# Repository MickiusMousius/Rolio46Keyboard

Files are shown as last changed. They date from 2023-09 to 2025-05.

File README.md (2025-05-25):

# Introduction
The Rolio46 is now at the version 1.1 release! This repo contains all the design files so you can build your own Rolio46.

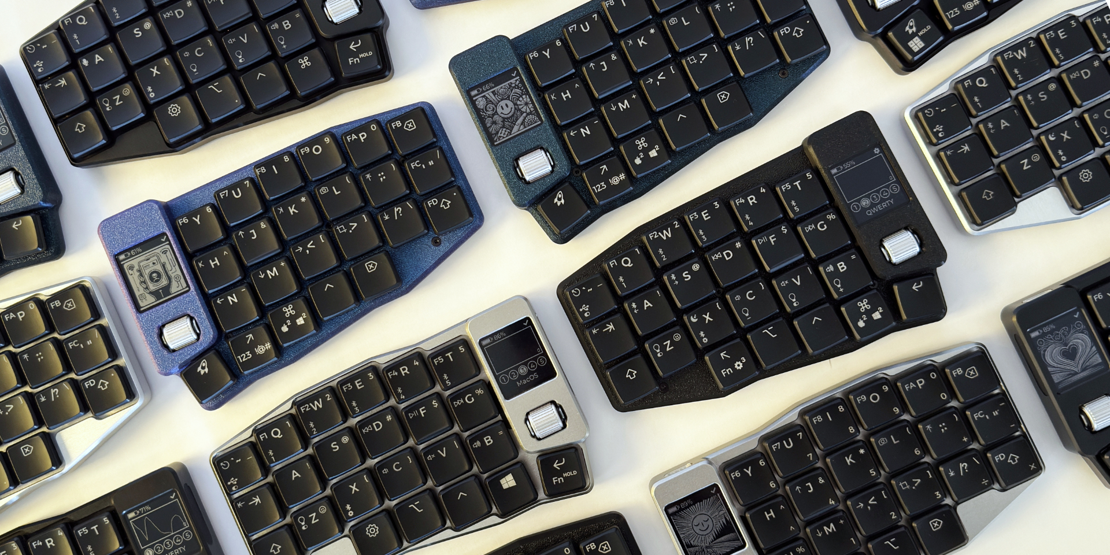
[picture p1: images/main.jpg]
Rolio46


If you'd like to build your own Rolio46 you can find resources at the following two links:
 * [RolioFirmware](https://github.com/MickiusMousius/RolioFirmware) - Firmware & user documentation for the Rolio46
 * [Keydio.io](https://keydio.io) - Online store to buy a complete kit or just some parts to build your own Rolio46

# Features
The keyboard itself:
- Fully wireless thanks to the awesome [ZMK Project](https://zmk.dev)
- Support for [ZMK Studio](https://zmk.studio/download)
- Excellent battery life, I've personally been getting 4+ weeks before it needs charging
- A low profile, compact choc spaced form factor that is similar to the Corne
- Additional "Sometimes" buttons on the bottom row just like the Sofle
- Horizontal roller encoders on both halves
- A backlight that is efficient enough to be used on battery
- A robust chassis so that it can be treated like a normal keyboard
  - An FDM version for at home low cost at home production
  - A CNC option for a slick look and very premium feel
- A travel case that can easily be made using any FDM printer

ZMK Key map & Custom key caps:
- Up to five memorized bluetooth profiles and a wired mode
- MacOS and Windows layouts as part of the key map to keep the "same" handy behaviors in both OSs
- Able to memorize a specific OS layout for each profile, when you change bluetooth profiles it'll remember whether to use a Windows or MacOS layout
- All of the symbols and special behaviors can be accessed using at most two keys.
- The key caps are fully customized and match the ZMK key map thanks to [FKCaps](https://fkcaps.com/custom/UCR89J?a=KeydioDiscount)
- The settings keys and different modes are documented in the key caps themselves (easy to learn).

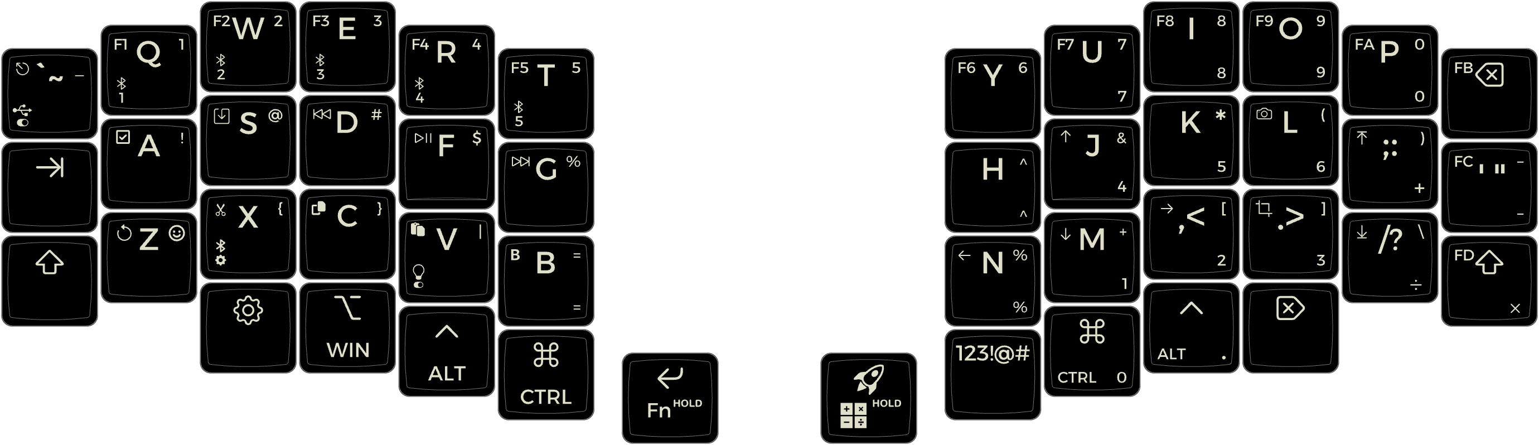
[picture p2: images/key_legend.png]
Version 1.1 Key Caps (https://fkcaps.com/custom/UCR89J?a=KeydioDiscount)
  

# Firmware

You can download the latest firmware from here: [Rolio46 Firmware](https://github.com/MickiusMousius/RolioFirmware)

When you push a change to your fork a GitHub action will create a new firmware build for you.

If you want to do basic layout customization then [ZMK Studio](https://zmk.studio/download) should be all you need.

# Build Resources
In order to build a Rolio46 you will need 5 main sub assemblies, the links below provide information about the different sub assemblies:
 * [The controller](doc/controller.md)
 * [The display](doc/display.md)
 * [The battery](doc/battery.md)
 * [The shield](pcb/README.md)
 * [The chassis](chassis/README.md)

The shield and chassis are the sub assemblies that are most unique to this project, all of the other sub assemblies are fungible.

# Other Components

<ins>Keycaps</ins>

This keyboard has been designed to use MBK caps. You should however be able to use any Choc compatible compatible caps.

You can order a set of custom key caps from a number of possible suppliers too.

I have a design at FKCaps that has the key map of this board integrated into the keys. The link for this key cap set can be found [HERE](https://fkcaps.com/custom/UCR89J?a=KeydioDiscount).

<ins>Switches</ins>

The Rolio46 is designed for use with Choc V1 switches, these can be purchased from many different vendors. My personal favorite switch is the "Choc Sunset" switch.

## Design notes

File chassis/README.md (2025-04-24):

# Introduction

This folder contains a designs and manufacturing files for the Rolio46 keyboard chassis.

The folders within here are described below.

## Electronics

This contains STEP file models with the electronics and PCB. These can be used when creating new chassis or modifying the existing models.

## CNC

This is by far the most expensive of the two options. It is also the most aesthetically pleasing, rigid and durable choice.

It does have the drawback of being the heaviest.

More information and preview images can be found in the [CNC Section](cnc/README.md).

## FDM

Contains design files for a FDM 3D printed chassis.

This is the most accessible manufacturing option and the cheapest.

The largest drawback of this manufacturing technique is that layer lines may be visible. Additionally the chassis may not be as rigid as desired depending on the filament used.

More information and example images can be found in the [FDM Section](fdm/README.md).

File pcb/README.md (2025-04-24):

# Introduction

This folder contains the KiCad 7 PCB design files for the left and right shield boards of the Rolio 46.

# Ordering The PCBs from JLCPCB

Inside the "Left" and "Right" folders there are "Gerbers" zips. These are gerber files that have been prepared for use with JLCPCB.

The following settings were used when ordering:
* Base Material:	FR-4
* Layers:	2
* Delivery Format:	Single PCB
* PCB Thickness:	1.6
* Impedance Control:	No	
* PCB Color:	Black
* Silkscreen:	White
* Via Covering:	Tented
* Surface Finish:	HASL(with lead)
* Deburring/Edge rounding:	No
* Outer Copper Weight:	1 oz
* Gold Fingers:	No
* Flying Probe Test:	Fully Test
* Castellated Holes:	No
* Remove Order Number:	No
* 4-Wire Kelvin Test:	No
* Paper between PCBs:	No
* Appearance Quality:	IPC Class 2 Standard
* Silkscreen Technology:	Ink-jet/Screen Printing Silkscreen
* Board Outline Tolerance:	±0.2mm(Regular)

Ordering is possible with other suppliers, however you should regenerate the Gerber files according to the manufacturer's requirements.

<br/>

# Required Components

All of the components in the below table are required to build the shield assembly.

| Quantity  | Description  | Ref  | Value  | Supplier  |
|:---|:---|:---|:---|:---|
| 48 | 75V 0.15A Fast Switching Diode, SOD-123 | D1-D29 | 1N4148W | [Aliexpress](https://www.aliexpress.com/item/4000685043735.html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 ) |
| 2  | Machine sockets and pins | - | - | [Typeractive](https://typeractive.xyz/products/machine-sockets-and-pins?_pos=1&_sid=3c03709e0&_ss=r) |
| 2 | Surface mount push button switch, generic, two pins | RESET1 | - | [Aliexpress](https://www.aliexpress.com/item/1005004297433455.html?spm=a2g0o.order_list.order_list_main.136.675e1802ITKJQ5 ) (I used "Option 4")  |
| 2  | Surface mount DIP Switch, Single Pole Single Throw (SPST) switch, small symbol | SW4  | - | [Aliexpress](https://www.aliexpress.com/item/4000685483225.html?spm=a2g0o.order_list.order_list_main.177.675e1802ITKJQ5) |
| 2  | EVQWGD001 Rotary encoder, dual channel, incremental quadrate outputs, with switch  | RE_1  | EVQWGD001  | [Aliexpress](https://www.aliexpress.com/item/1005004320540116.html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 ) |
| 4  | 0805 Surface mount capacitors  | C1, C2  | 100nF  | [Aliexpress](https://www.aliexpress.com/item/32888863725.html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) |
| 46  | Kailh Choc hot swap sockets PG1350 | - | -  | [Aliexpress](https://www.aliexpress.com/item/1005003908487064.html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) |

<br/>

# Optional Backlight Components

The parts in the below table are only needed for the backlight, if you do not want a backlight they can be omitted from your build to save some money.

| Quantity  | Description  | Ref  | Value  | Supplier  |
|:---|:---|:---|:---|:---|
| 2 | 30V Vds, 5.7A Id, N-Channel MOSFET, SOT-23  | Q1 | AO3400A | [Aliexpress](https://www.aliexpress.com/item/33013971929.html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)  |
| 2 | 0805 Surface mount resistor  | R1  | 470Ω  | [Aliexpress](https://www.aliexpress.com/item/1005001794062302.html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) |
| 2 | 0805 Surface mount resistor  | R2  | 10kΩ  | [Aliexpress](https://www.aliexpress.com/item/1005001794062302.html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) |
| 46 | 0805 Surface mount resistor  | R3-R25 | 680Ω  | [Aliexpress](https://www.aliexpress.com/item/1005001794062302.html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) |
| 46  | 0805 Surface mount LED  | LED1 - LED23  | - | [Aliexpress](https://www.aliexpress.com/item/1005004341345794.html?spm=a2g0o.order_list.order_list_main.25.675e1802ITKJQ5 )  |

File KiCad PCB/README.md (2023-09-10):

# Introduction

This folder contains the KiCad 7 PCB design files for the left and right halves of the Rolio Keyboard.

# Ordering

Inside the "Left" and "Right" folders there are "Gerbers" folders. These are gerber files that have been prepared for use with JLCPCB.

The two "Gerbers" folders can be zipped independently and uploaded to JLCPCB for ordering.

The following settings were used when ordering:
* Base Material:	FR-4
* Layers:	2
* Delivery Format:	Single PCB
* PCB Thickness:	1.6
* Impedance Control:	No	
* PCB Color:	Black
* Silkscreen:	White
* Via Covering:	Tented
* Surface Finish:	HASL(with lead)
* Deburring/Edge rounding:	No
* Outer Copper Weight:	1 oz
* Gold Fingers:	No
* Flying Probe Test:	Fully Test
* Castellated Holes:	No
* Remove Order Number:	No
* 4-Wire Kelvin Test:	No
* Paper between PCBs:	No
* Appearance Quality:	IPC Class 2 Standard
* Silkscreen Technology:	Ink-jet/Screen Printing Silkscreen
* Board Outline Tolerance:	±0.2mm(Regular)

Ordering is possible with other suppliers, however you should regenerate the Gerber files according to the manufacturers requirements.

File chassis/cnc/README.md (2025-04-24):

# Introduction

This section contains all of the files and information that is needed to manufacture a CNC Rolio46.1/46.2 chassis.

The STEP files are the original CAD files, these are made available so that modifications can easily be made. If the STEP files from the Electronics folder are imported too it will be possible to see the clearances for various parts.

# Example

Purple backlight LED's with dark anodized aluminium & tenting stand.

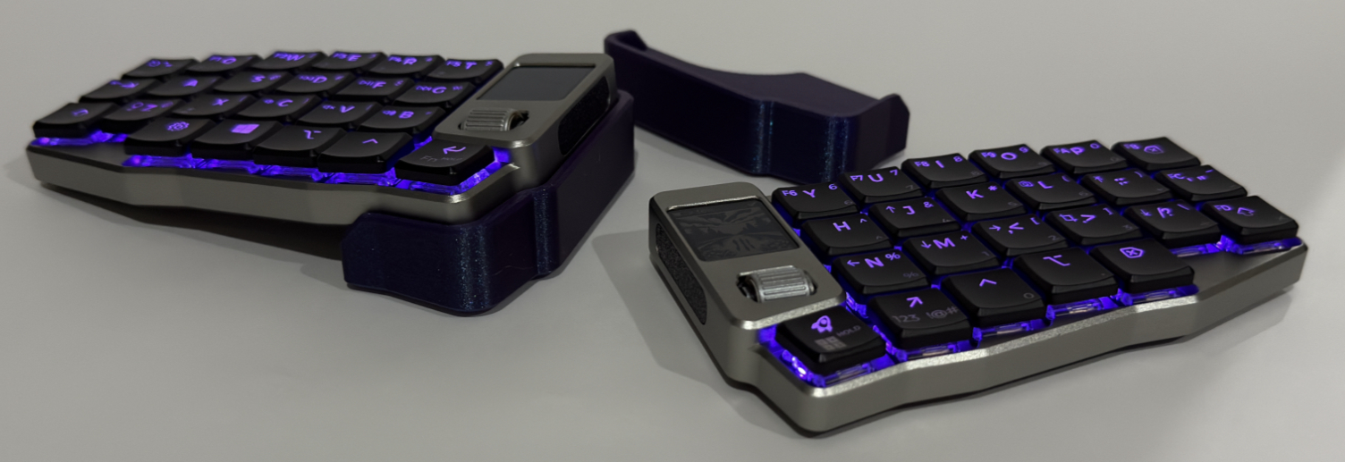
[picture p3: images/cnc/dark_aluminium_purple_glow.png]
CNC Rolio46.3 Example with Tenting Stand


# Main Chassis

The STEP files in "CNC Parts" must be uploaded to provide the design itself.

When preparing the order use the following settings:
 * Material 6061 Aluminum
 * Finish
   * Bead Blasting - 120 mesh
   * Glossy Anodizing - Natural
 * Tolerance ISO 2768 medium
 * Threads "Yes"
   * Upload the "Thread and Machine Spec.pdf" to provide thread details

You will need to request a manual quote from JLCPCB before you can proceed to place your order.

In addition to the CNC parts some components need to be printed using FDM. The required printing files can be found in the "3D Printing" folder, you will TPU & PLA filaments.

To complete assembly you will need the following additional hardware:

| Quantity  | Description  | Ref  | Value  |
|:---|:---|:---|:---|
| 8  | 9mm Silicone Feet | -  | - |
| 10 | M2x4mm Screws | -  | -  |

# Travel Case

A travel Case is also available for the Rolio46.1/46.2. All of the files required to print your own are available in the "Production Files" folder.

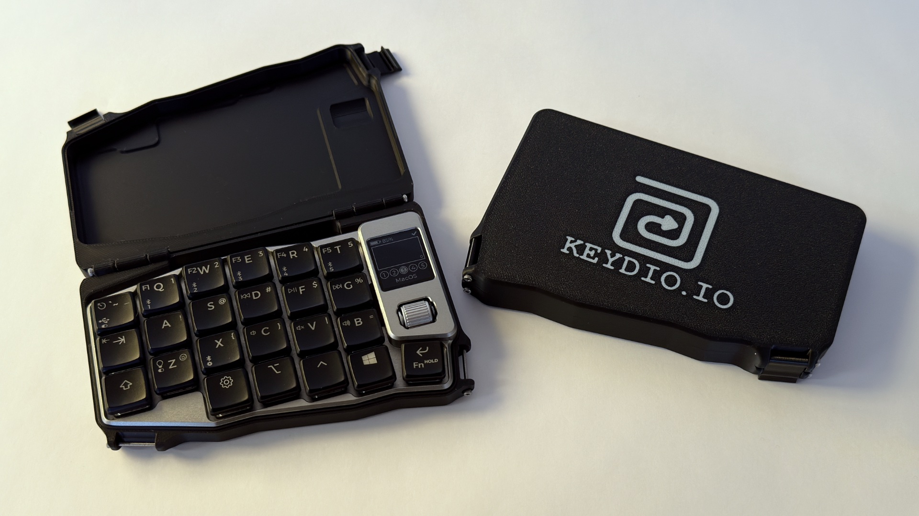
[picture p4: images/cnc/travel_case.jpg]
CNC Rolio46.3 Example with Travel Case


To complete the travel case you will need some additional small hardware items:

| Quantity  | Description  | Ref  | Value  |
|:---|:---|:---|:---|
| 4 | M2x30mm Screws | -  | - |
| 8 | M2x20mm Screws | -  | -  |

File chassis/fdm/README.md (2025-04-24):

# Introduction

This is a chassis that can be printed using a conventional FDM (filament) printer without needing supports for the critical components.

It has been tested using a Bambu Labs X1C with a 0.4mm nozzle.

The STEP files are the original CAD files, these are made available so that modifications can easily be made. If the STEP files from the Electronics folder are imported too it will be possible to see the clearances for various parts.

# Example

Printed in Voxelab Galaxy PLA.

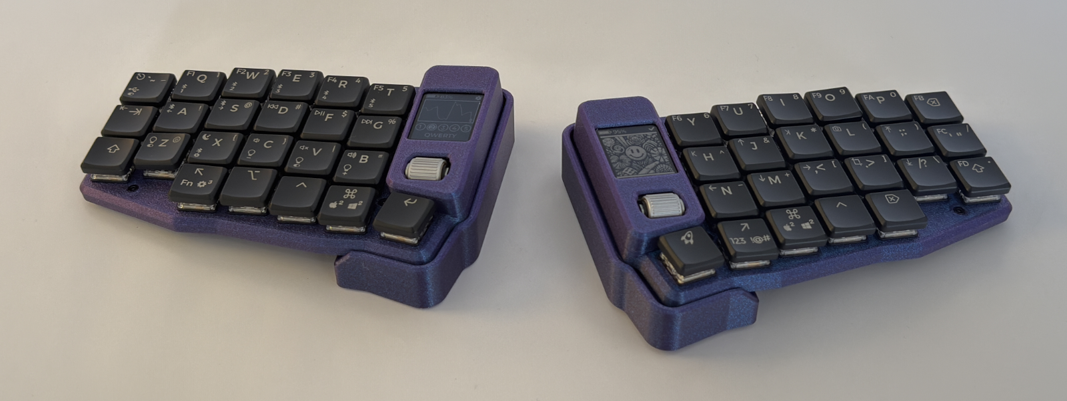
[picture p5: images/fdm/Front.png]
FDM Rolio46.2 Example


# The Chassis

The prnting file was prepared using Bambu Studio and should be compatible with OrcaSlicer too.

If you wish to prepare your own print files th original CAD models are included in this repo.

The "Top Plate" &  "Controller Cover" should be printed face down with supports disabled.

The bottom plate can be printed in its natural orientation.

The "USB Diffuser" is optional, if it is printed it should ideally be printed in clear filament so that light from the LED indicators can shine through.

Additional Hardware:

| Quantity  | Description  | Ref  | Value  |
|:---|:---|:---|:---|
| 8  | 9mm Silicone Feet | -  | - |
| 24 | M2x4mm Screws | -  | -  |
| 10 | M2x3 Brass standoffs | - | - |

# Travel Case
A travel Case is also available for the Rolio46.1/46.2. All of the files required to print your own are available in the "Production Files" folder.

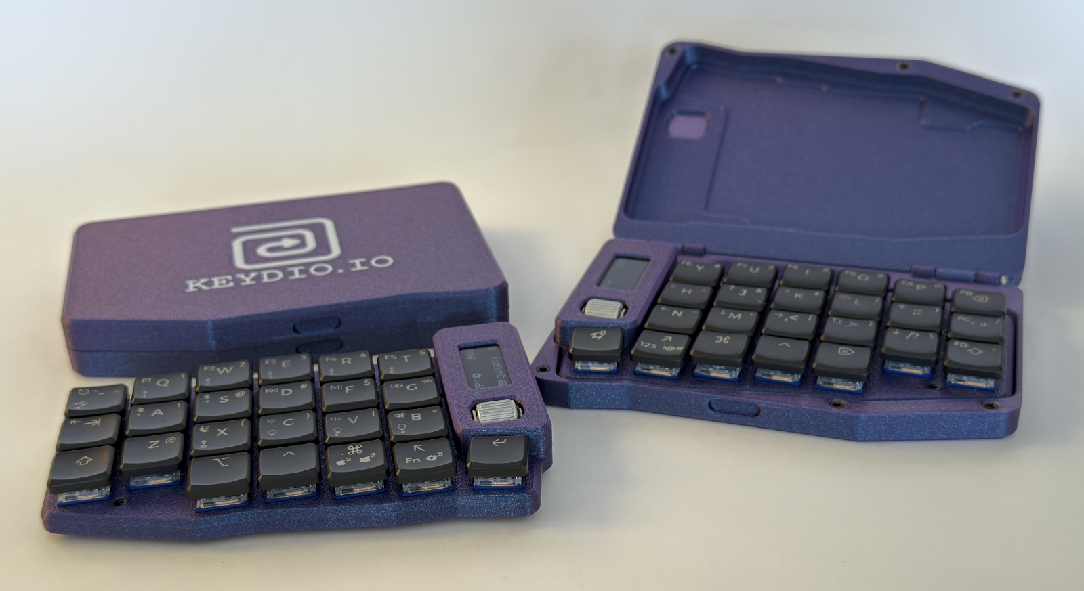
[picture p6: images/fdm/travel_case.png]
FDM Rolio46.1 Example


To complete the travel case you will need some additional small hardware items:

| Quantity  | Description  | Ref  | Value  |
|:---|:---|:---|:---|
| 4 | M2x30mm Screws | -  | - |
| 8 | M2x20mm Screws | -  | -  |

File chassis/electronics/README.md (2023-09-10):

These STEP files are the original PCB + Parts export from KiCad.

If the STEP files from the Electronics folder are imported to any of the chassis models it will be possible to see the clearances for various parts.

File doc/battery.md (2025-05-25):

# Introduction

The Rolio46.1 is designed to use a small rechargeable lithium battery with charging provided by the [controller](controller.md).

# The Batteries

Only protected cells should be used with the Rolio46. Additionally, you should only purchase batteries that are reasonably known to be of good quality.

The [shield boards](../pcb/README.md) have been designed to accommodate a protected 801230 battery below the controller, however, a 701230 battery would likely also fit quite well, though may require securing with Kapton tape.

I have tested the Liter Energy 801230 batteries, their capacity consistently tests a little over 250mAh. The battery type that has been tested is photographed below:

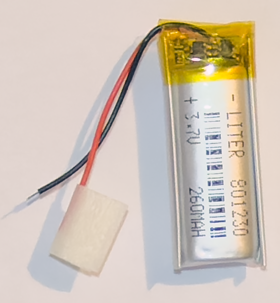
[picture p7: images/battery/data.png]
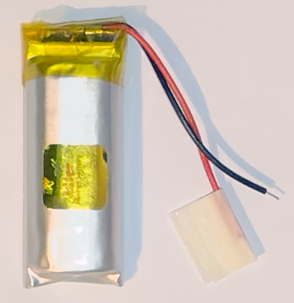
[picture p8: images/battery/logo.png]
|||

I have found that these batteries can provide more than a month of normal usage with a Nice!Nano controller.

I have ordered my batteries from [Bihuade](https://www.aliexpress.com/item/1005005386757680.html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) ([Alternative](https://bihuade.com/products/37v-260mah-801230-liter-energy-battery-rechargeable-polymer-lithium-ion-battery-for-drone-dvr-power-bank-speaker)).

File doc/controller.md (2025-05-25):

# Introduction

The controller provides the "brains" for the Rolio46 keyboard. All of the tested controllers provide the Bluetooth connectivity as well as battery charging and USB functionality. 

The following page as some excellent information regarding various controller options: https://github.com/joric/nrfmicro/wiki/Alternatives

# Controllers

There are three different controllers that have been tested with this project.

| Nice!Nano  | Mikoto | SuperMini 52840 | 52840Nano |
| --- | --- | --- |--- |
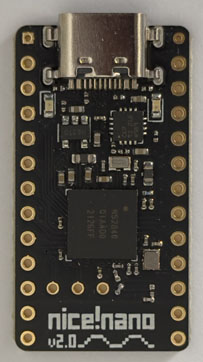
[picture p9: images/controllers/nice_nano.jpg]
Nice!Nano
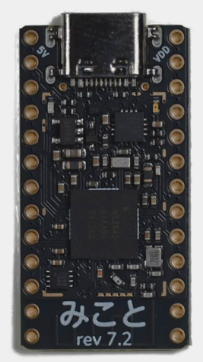
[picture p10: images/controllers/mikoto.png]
Mikoto
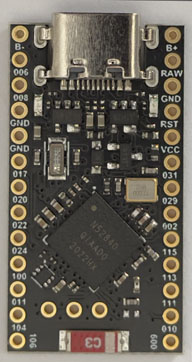
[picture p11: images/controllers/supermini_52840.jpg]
SuperMini NRF52840
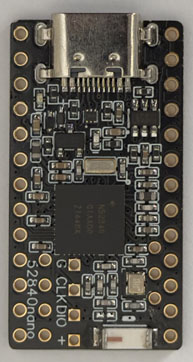
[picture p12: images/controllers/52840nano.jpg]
52840Nano
|   |   |   |   |

Details for each controller are summarized below.

### Nice!Nano V2

This is the most common of the available controllers. Documentation for this controller can be found on [nice keyboards](https://nicekeyboards.com/nice-nano/).

The most standout features are summarized below:
 * Deep sleep consumption of only 20uA
    * This could provide a theoretical standby time (if not used) of more than 12 months for a Rolio46
 * High manufacturing standards
 * Well established & widely used so its behavior is very well understood

This is a good all round controller. It has an excellent power consumption profile, has good support for all required features and is readily available from many distributors.

### Mikoto rev 7.2

TIn my opnion the best of the available controllers. Documentation for this controller can be found on the [Mikoto GitHub](https://github.com/zhiayang/mikoto).

The most standout features are summarized below:
 * Excellent battery life, more than 4 weeks of usage with a Rolio46
 * Uses a battery fuel gauge (MAX1748) so provides much better battery reporting than a nice!nano and many of its clones
 * Has an excellent power path management design

The largest drawback to this controller is that it is not in common use & ony appears to be available from a [single vendor](https://keebd.com/products/mikoto-controller) (though, a very good vendor). The Rolio46 has a build target for the Mikoto that is actively tested/used.

### SuperMini NRF52840

This is essentially a Nice!Nano clone, testing shows that it is almost 100% compatible with the Nice!Nano. Further documentation on this controller can be found on [ICBuy](http://wiki.icbbuy.com/doku.php?id=developmentboard:nrf52840).

Testing has shown that the deep sleep power consumption when turning off the external peripherals is as high as 700uA, this would provide very poor deep sleep durations. However this can be worked around by disabling peripheral power control this will decrease deep sleep power consumption to 128uA.

Key details are summarized below:
 * Deep sleep consumption of 128 uA
    * This could provide a theoretical standby time (if not used) of roughly 80 days for a Rolio46
 * Poor support for peripheral power control
 * Much cheaper than the Nice!Nano

This controller is a good choice for those that type for several hours a day that are more price conscious. The Rolio46 can provide a little over 2 weeks of use between charges with this controller (depending on backlight usage etc). For a high usage scenario this controller's power profile is roughly comparable to the Nice!Nano.

### 52840Nano

*DANGER: This has been tested to mostly work, however, it has an unregulated peripheral power pin. Whilst it appears to mostly work it will eventually destroy your display.*

Another Nice!Nano Clone, as with the SuperMini 58240 testing shows that it is almost fully compatible with the Nice!Nano.

There is one key issue with the controller, it can not power the Rolio46's back light circuit. There are no work arounds for this except to disable the backlight in firmware.

Key details are summarized below:
 * Not compatible with the Rolio46.1 backlight circuit, requiring the backlight to be disabled in firmware.
 * Standby power consumption of just 2.5uA
 * Requires a modification to the ZMK firmware to get accurate battery readings
 * Much cheaper than the Nice!Nano

I do not recommend the use of this controller unless you are building a version with no display or backlight.

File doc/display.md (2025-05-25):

# Introduction

The display module provides an easy way for you to know if your Rolio46 halves are connected and talking to each other properly as well as your charge state and PC connection status.

Whilst the displays are technically optional I'd not recommend building a Rolio46 without a display on each half.

# Displays

Three different display modules have been tested with the Rolio46. All of these display modules are based on Sharp's memory display technology so offer excellent power consumption profiles.

| Vista508 | Nice!View  | Vista272 |
| --- | --- | --- |
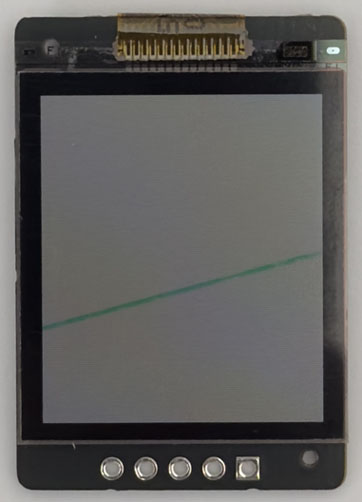
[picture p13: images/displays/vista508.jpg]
Vist508
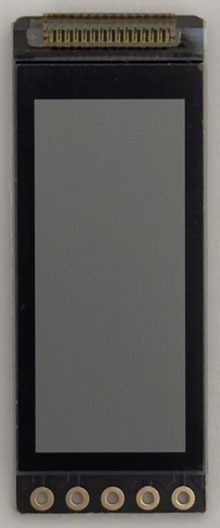
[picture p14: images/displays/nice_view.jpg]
Nice!View
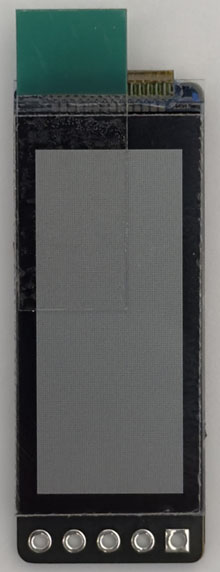
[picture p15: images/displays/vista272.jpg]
Vista272
|  |   |   |

Relevant details for each controller are roughly summarized below.

### Vista508

The Vista508 is a wider version of the Vista272/nice!view, its electrical characteristics are very similar.

The key details of the Vista508 display are as follows:
 * Display area of 20.88x24.36mm
 * 144x168 pixels
 * Power consumption (Typical - Maximum)
   * Fixed image: 25-125uW (7.5-38uA)
   * Updating image at 1 frame per second (30 fps supported): 35-150uW (10-45uA)
 * [Data sheet for display module](https://www.sharpsecd.com/static/media/Sharp-LCD-Specification-LS013B7DH05-12-17-19.4f9deb60.pdf)

The Rolio46 firmware has full support for the Vista508 as well as some useful Python scripts to help customize peripheral artwork.

### Nice!View

The Nice!View is the most common of the available displays and is available from many distributors. Documentation on the Nice!View can be found on the [Nice Technologies website](https://nicekeyboards.com/docs/nice-view/).

The key details of the Nice!View display are as follows:
 * Display area of 25.28x10.74mm
 * 160x68 pixels
 * Power consumption (Typical - Maximum)
   * Fixed image: 15-50uW (4.5-15uA)
   * Updating image at 1 frame per second (30 fps supported): 25-100uW (7.5-30uA)
 * [Data sheet for display module](https://www.sharpsde.com/fileadmin/products/Displays/Specs/LS011B7DH03_24Nov17_Spec_LD-29Y03.pdf)

### Vista272

The Vista272 is essentially a drop in replacement for the Nice!View display, it uses the exact same display module.

The key details of the Vista272 display are as follows:
 * Display area of 25.28x10.74mm
 * 160x68 pixels
 * Power consumption (Typical - Maximum)
   * Fixed image: 15-50uW (4.5-15uA)
   * Updating image at 1 frame per second (30 fps supported): 25-100uW (7.5-30uA)
 * [Data sheet for display module](https://www.sharpsde.com/fileadmin/products/Displays/Specs/LS011B7DH03_24Nov17_Spec_LD-29Y03.pdf)

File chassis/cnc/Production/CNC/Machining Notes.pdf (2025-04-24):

# Finishing Requirements

# Screw Mounting Hole Specifications

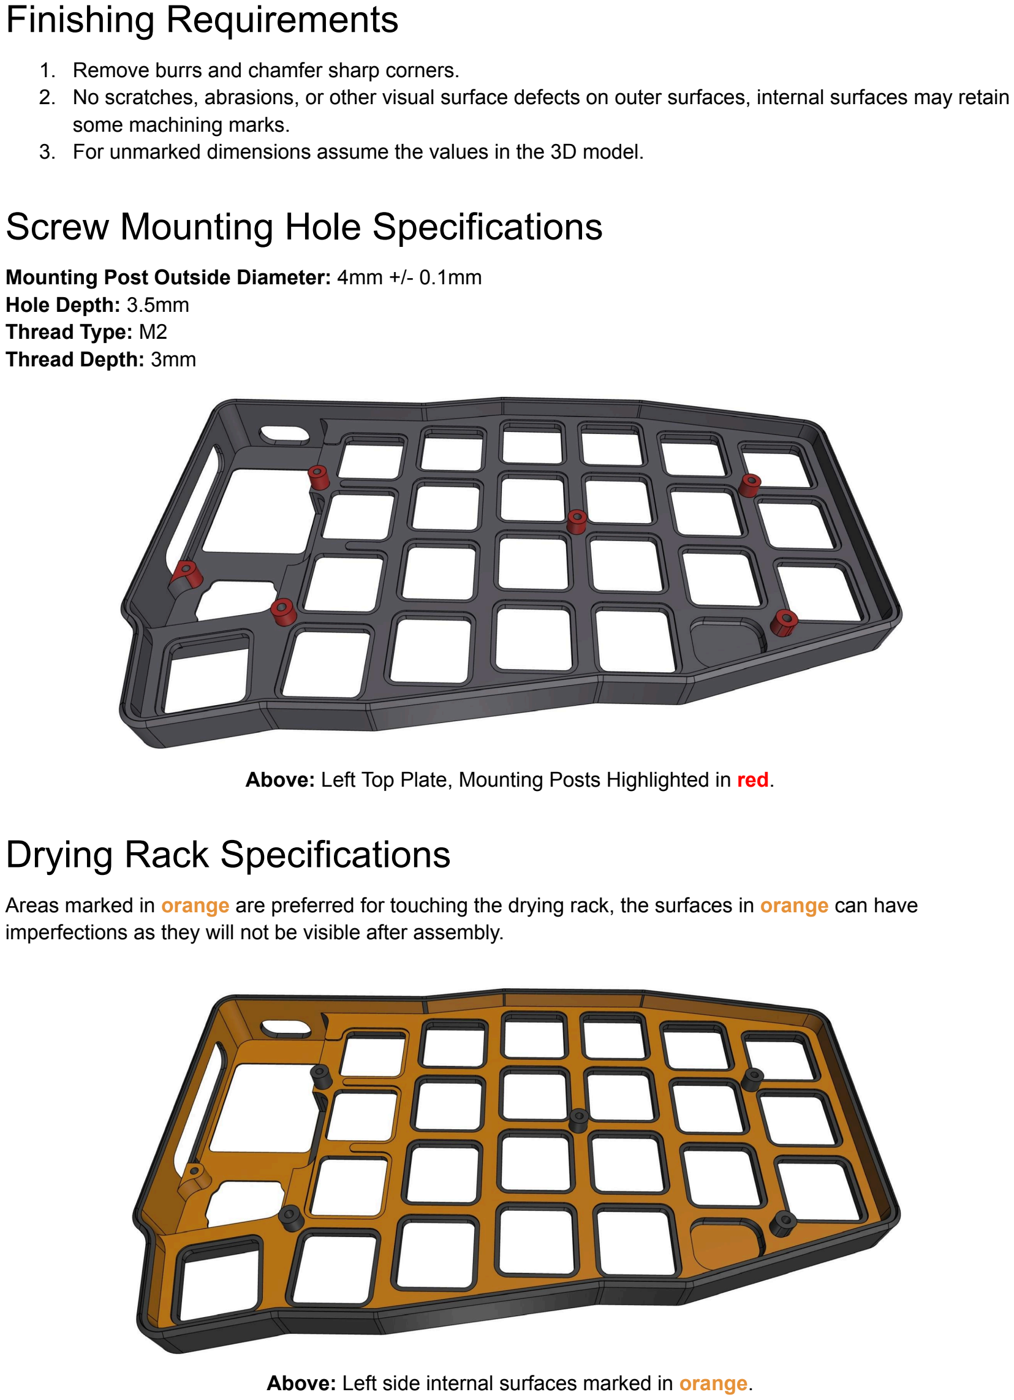
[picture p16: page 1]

1. Remove burrs and chamfer sharp corners.
2. No scratches, abrasions, or other visual surface defects on outer surfaces, internal surfaces may retain some machining marks.
3. For unmarked dimensions assume the values in the 3D model.

Mounting Post Outside Diameter: 4mm +/- 0.1mm Hole Depth: 3.5mm
Thread Type: M2
Thread Depth: 3mm

Above: Left Top Plate, Mounting Posts Highlighted in red.

# Drying Rack Specifications

Areas marked in orange are preferred for touching the drying rack, the surfaces in orange can have imperfections as they will not be visible after assembly.

Above: Left side internal surfaces marked in orange.

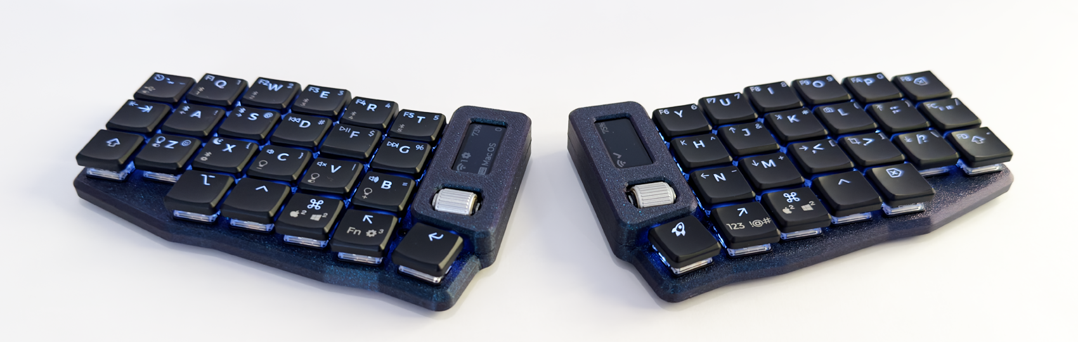
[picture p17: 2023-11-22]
images/fdm/backlight_on.png

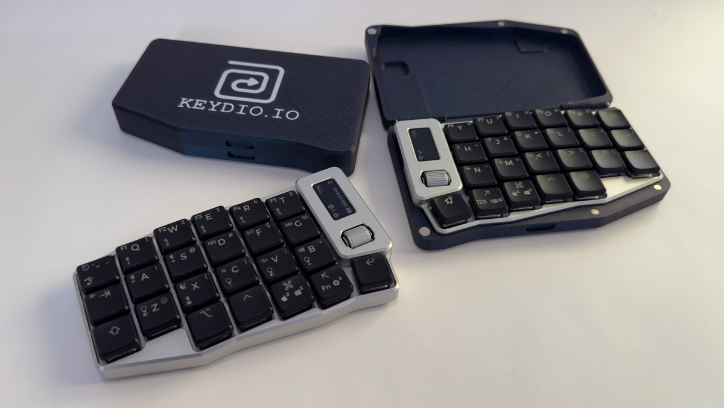
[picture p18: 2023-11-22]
images/case.png

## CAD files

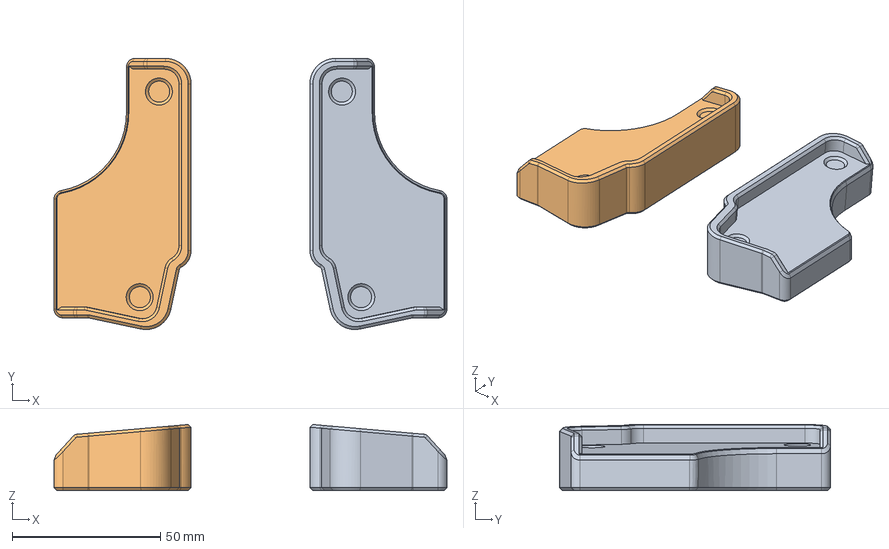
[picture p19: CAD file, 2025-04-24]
chassis/cnc/CAD Models/Tenting Kit.step
132.4 x 91.3 x 22.2 mm

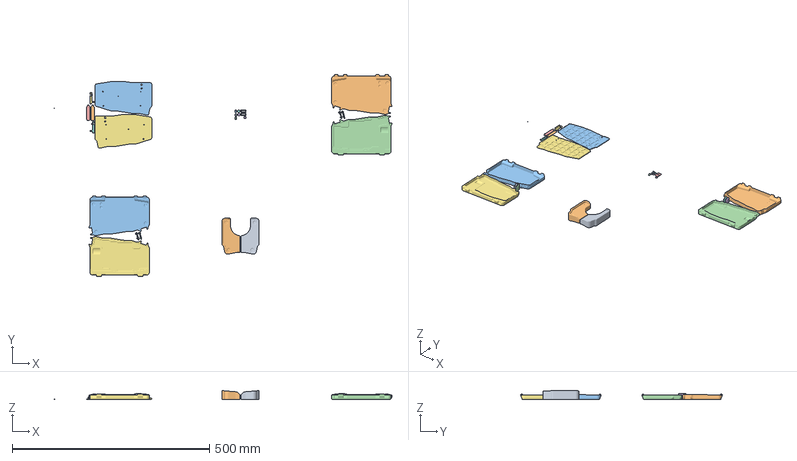
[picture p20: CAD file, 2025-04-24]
chassis/cnc/Production/3D Printing/3D Printing - PLA.3mf
856.1 x 510.6 x 22.2 mm
root_2
Left_2
Right_2
Left_1
Right_3 x 2
Left_4 x 4
Right_1
root_1
Left_11
Left_5 x 4
Right_10
Left_9
root x 3
Right_9
Right_8
Left_8
Left_7

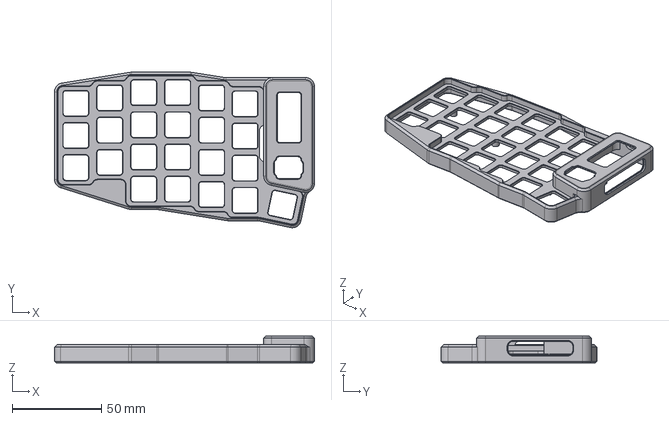
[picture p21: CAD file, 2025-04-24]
chassis/cnc/Production/CNC/Vista272 - Left.step
145.5 x 87.0 x 15.1 mm

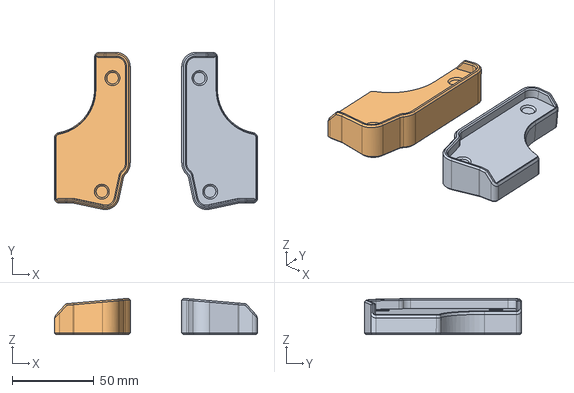
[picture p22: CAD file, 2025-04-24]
chassis/fdm/CAD Models/Tenting Kit.step
123.8 x 95.8 x 22.2 mm

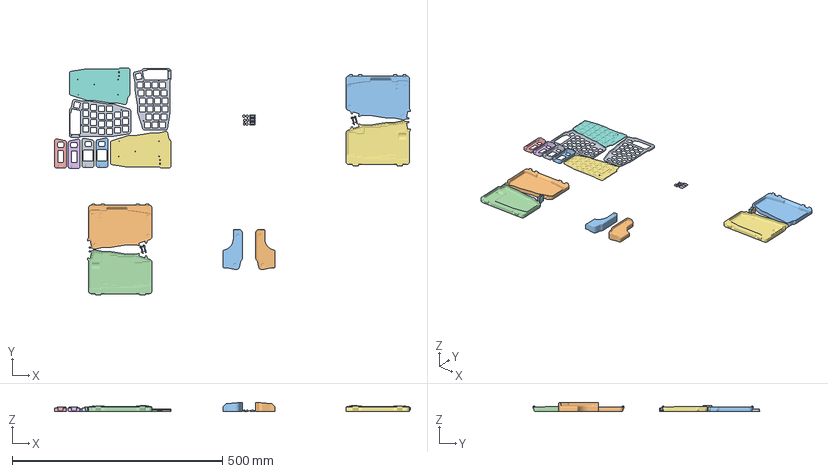
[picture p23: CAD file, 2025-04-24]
chassis/fdm/Production Files/3D Printing.3mf
845.7 x 539.4 x 22.2 mm
Right_1 x 2
Right_3
Left_3 x 2
Left_7 x 3
Left_4 x 5
Left_1 x 2
Right_5
Right_6
Right_7
Left_5 x 3
Left_2
root x 3
root_1
root_2

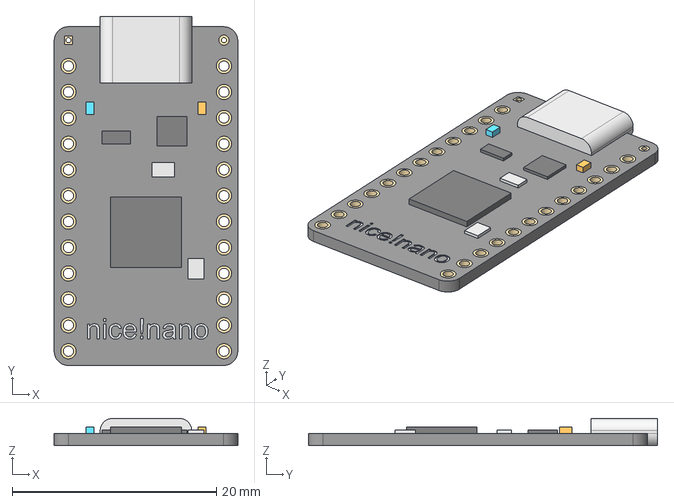
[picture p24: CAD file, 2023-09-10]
pcb/right/3D Models/Nice Nano.step
18.0 x 34.2 x 2.65 mm

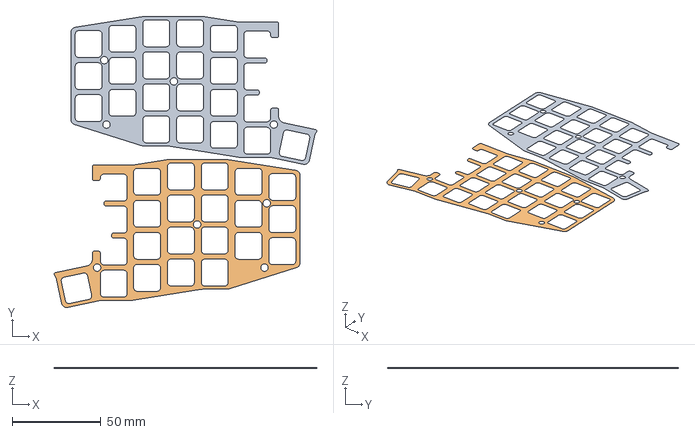
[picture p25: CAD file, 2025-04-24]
chassis/cnc/Production/3D Printing/3D Printing - TPU.3mf
147.6 x 163.5 x 0.52 mm
Left_10 x 2

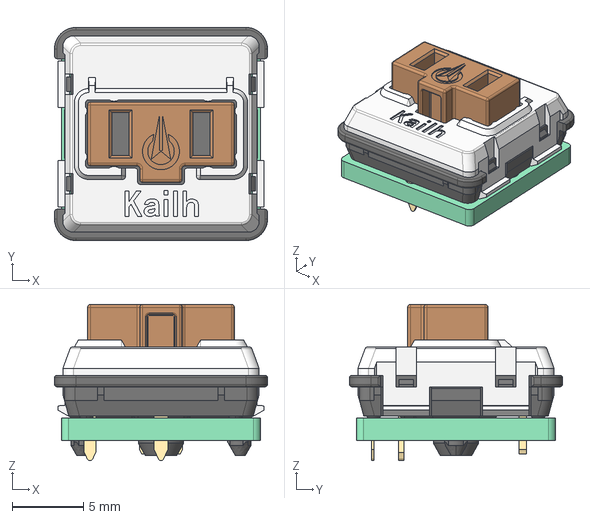
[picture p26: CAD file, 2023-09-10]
pcb/right/3D Models/pg1350.step
15.0 x 15.0 x 11.0 mm

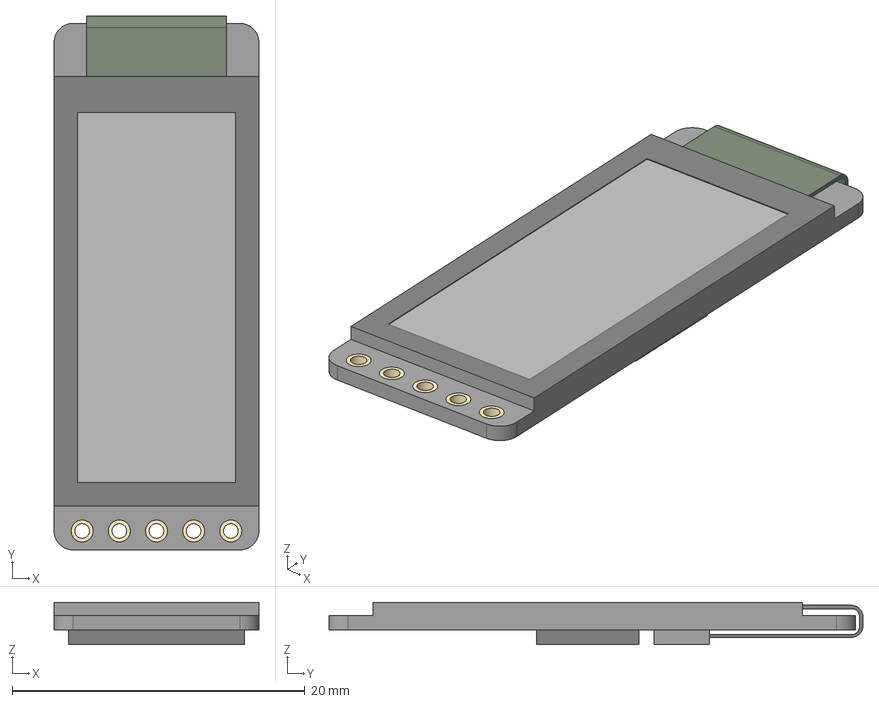
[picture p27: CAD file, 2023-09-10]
pcb/left/3D Models/Nice View.step
14.0 x 36.5 x 2.90 mm

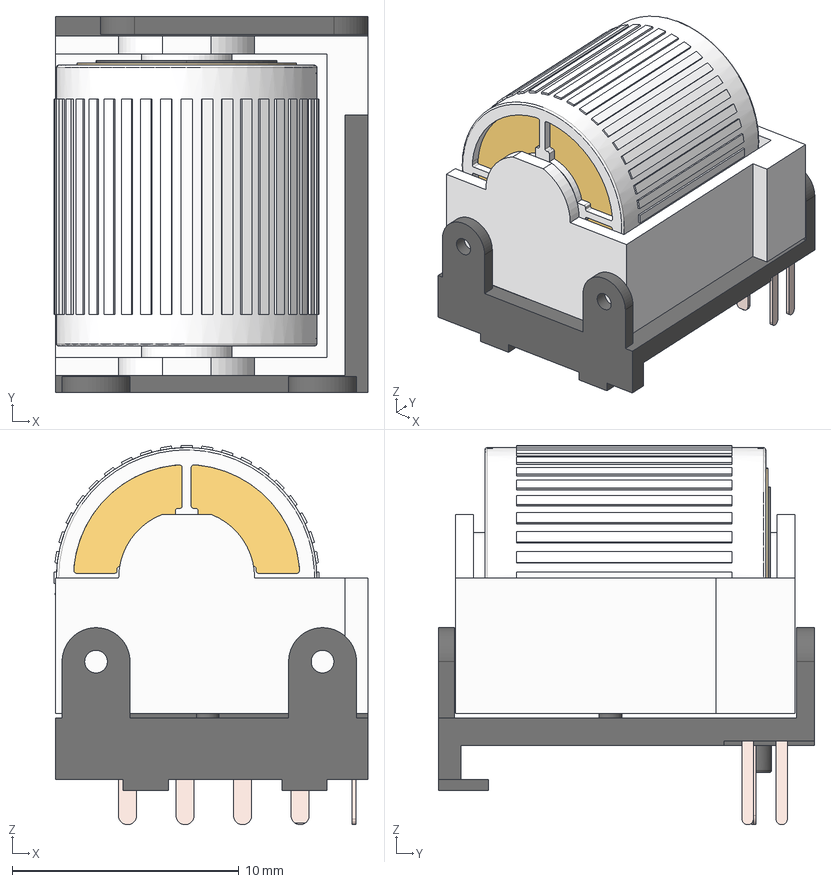
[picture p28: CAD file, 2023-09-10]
pcb/right/3D Models/EVQWGD001.step
13.9 x 16.6 x 16.8 mm
Plastic:1
Barrel in:1
Cap:1
Barrel out:1
Leg (1):1
housing:1
Leg (2):1
Leg (3):1
Plastic (1):1
Leg:1
Leg (4):1
Leg (5):1

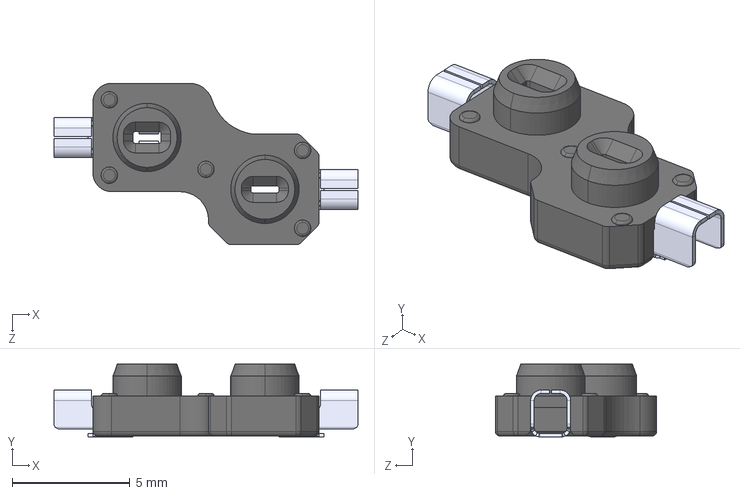
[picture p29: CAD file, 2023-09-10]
pcb/left/3D Models/PG1350-socket.step
12.9 x 3.09 x 6.85 mm
pin x 2
socket

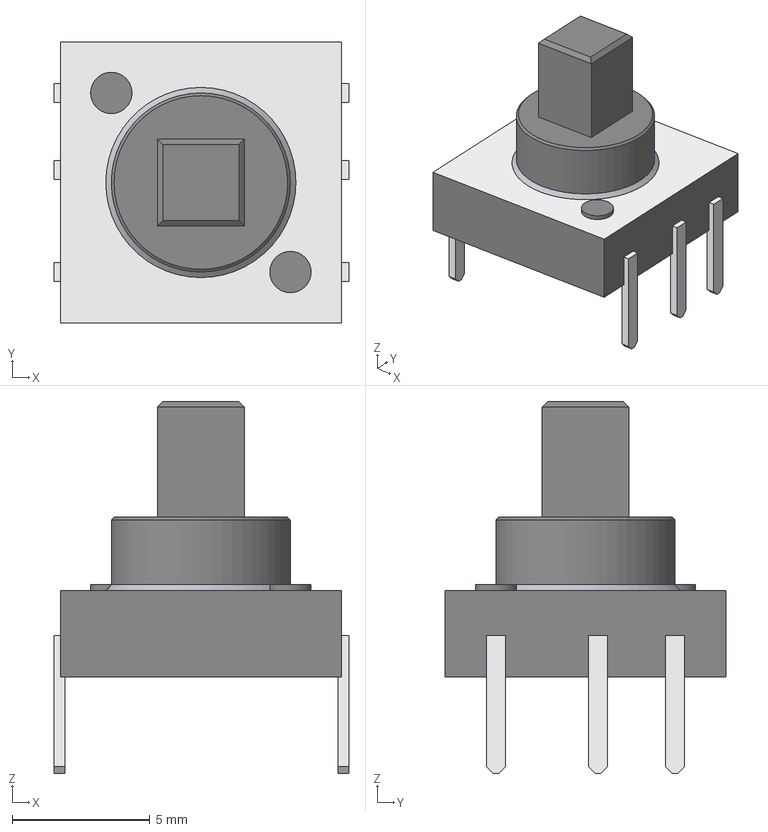
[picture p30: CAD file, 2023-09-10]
pcb/left/3D Models/LY-A07-12.step
10.7 x 10.2 x 13.5 mm

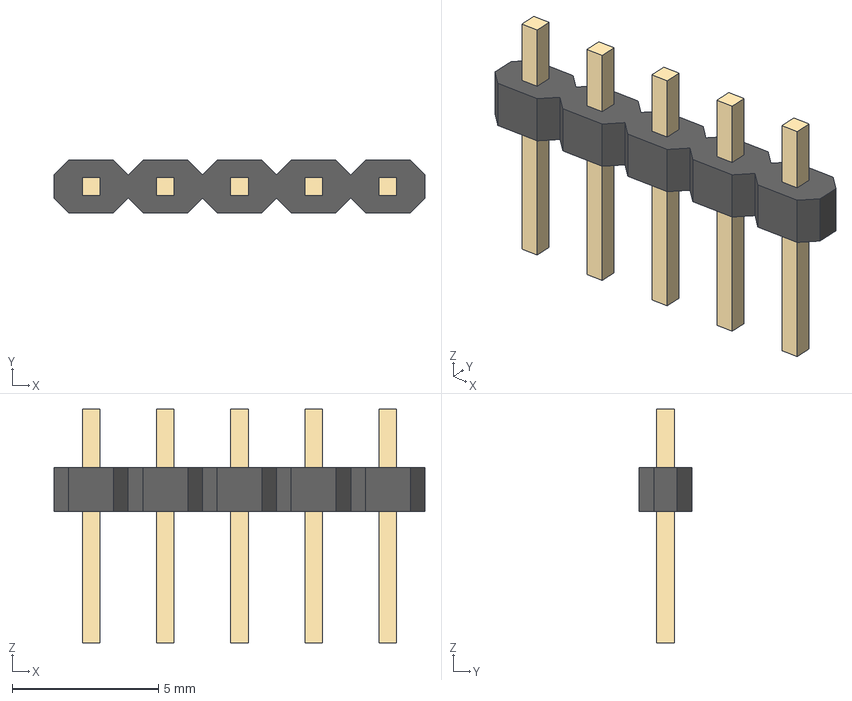
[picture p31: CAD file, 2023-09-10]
pcb/right/3D Models/Nice View Pin Headers.step
12.7 x 1.80 x 8.00 mm

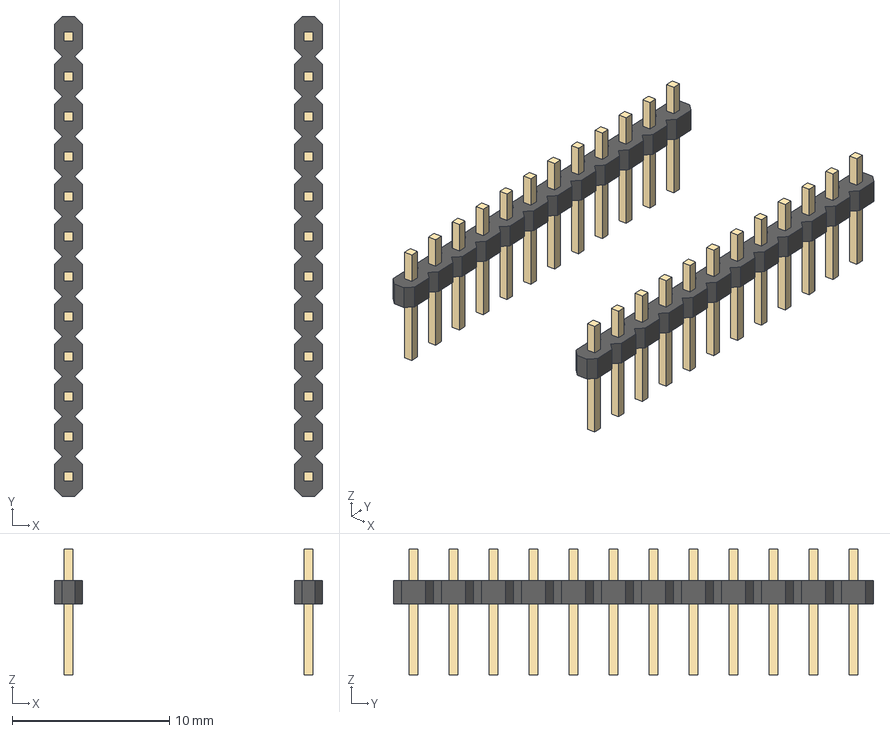
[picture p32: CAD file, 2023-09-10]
pcb/left/3D Models/Nice Nano Pin Headers.step
17.0 x 30.5 x 8.00 mm

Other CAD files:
chassis/cnc/Production/CNC/Vista508 - Left.step
chassis/cnc/Production/CNC/Vista272 - Right.step
chassis/cnc/Production/CNC/Vista508 - Right.step
pcb/left/3D Models/452403012014_Download_STP_452403012014_rev1.stp
pcb/left/3D Models/JS202011JCQN.stp
pcb/left/3D Models/pg1350-mbk.step
pcb/right/3D Models/pg1350-mbk.step

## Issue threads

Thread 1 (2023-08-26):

Display & encoder need to be moved outwards by roughly 1.5mm

MickiusMousius, 2023-08-26:
This will allow for the display to sit centrally when a housing sits around it.

Exact dimensional changes would need to be determined at design time as it is also a product of the chassis wall thickness,

Closed 2023-10-14.

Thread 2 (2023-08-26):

PCB netclass for the backlight circuit should use thicker traces

MickiusMousius, 2023-08-26:
The PCB net class is the same as the signal nets, this is fine due to the very low power of the backlight, however, as a matter of course it would be good to improve this to a slightly wider trace.

Closed 2023-10-14.

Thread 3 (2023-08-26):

Power switch should be under the PCB and have the "stem" at right angles

MickiusMousius, 2023-08-26:
The power switch is difficult to activate and increases assemble complexity.

Moving to a switch like the one below and placing it under the keyboard would improve reliability, ease of assembly and usability.

Suggested alternative: [MSS-22D18](https://www.aliexpress.com/item/4001161324412.html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,scm-url:1007.40050.354490.0,pvid:7704895e-736f-433c-a230-651fdc0dd4cc,tpp_buckets:668%232846%238107%231934&pdp_npi=4%40dis%21AUD%211.41%211.27%21%21%210.89%21%21%402103200516930223693824238e54d6%2110000014947791908%21rec%21AU%21%21A)

Closed 2023-10-14.

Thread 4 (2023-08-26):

Components could be better optimised for "mass assembly"

MickiusMousius, 2023-08-26:
The back resistors and rive circuit could be moved to the underside of the PCB.

In doing so reflow soldering could be used to affix more of the PCB components, thus reducing assembly time (or cost).

Only through hole components and the backlight LEDs would need to be soldered by hand this way.

Closed 2023-10-14.

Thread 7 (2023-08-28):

Roller encoder foot print PCB cut out is too small

MickiusMousius, 2023-08-28:
The hole cutout needs to be 0.1mm closer to the pins and 0.25mm wider to ease installation of the encoders.

Closed 2023-10-14.

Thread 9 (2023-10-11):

Version 1.0 Purchase Requests

dickiedyce, 2023-10-11:
Is there somewhere we can note our interest in purchasing v1.0 ?

MickiusMousius, 2023-10-11:
Not yet, I'll set something up tonight using Google forms though.

As a point of curiosity would you be wanting a fully built unit or a kit? Also, would you want the aluminium chassis or a plastic one?

MickiusMousius, 2023-10-13:
Hey, I finally got the survey done, I needed too set up a company for a few bits first.

Link below: https://forms.gle/bdBZMKoUopvWX2VN7

If this works for you I'll post it more visibly soon.

dickiedyce, 2023-10-18:
I have used the form - really great. Put me down for 4 !

dickiedyce, 2023-10-18:
I've just seen it on KBD News - https://kbd.news/Rolio-0.9-2158.html

MickiusMousius, 2023-10-19:
Ha, that's cool.

There's even a picture of the prototype travel case! I maybe should have re-printed the case with the fixed up logo.

I can see you've answered the survey, thank you. If you do genuinely want one of these boards (though you do say 4) I can probably get you at least one soonish, I have 6 aluminium chassis coming from JLCPCB soon. I could sell you one as an early test, if you really like it I can do more after, with some potential for limited customisation if you'd like (LED and chassis colour for example).

Let me know here if you're keen and I'll email you directly with more information.

dickiedyce, 2023-10-19:
That would be FANTASTIC!
I say 4, but I don't want to appear greedy ;-) . I have a Corne-ish Zen, which I love, but I only managed to get one, and it's awkward for work & home. If it's a limited run, I completely understand that from your point of view, more users is better...
But .... your extra keys and scrollers just looks cracking.

Closed 2023-10-14.

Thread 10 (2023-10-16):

Can you help me with this problem?

mozixun-me, 2023-10-16:
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
What method do you use to extend the Type-C interface in the part circled in the picture?

MickiusMousius, 2023-10-16:
It’s just a 3D printed shroud, I’ve attached a CAD picture that shows it (hopefully).

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

Closed 2023-10-17.

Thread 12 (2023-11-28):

Case sensitivity issues in the repo

AndrewMSHowe, 2023-11-28:
Hi, I need this keeb so badly :) But I noticed while cloning that there are some files/paths that are only distinguished by case. No doubt you're on Linux or whatevs, but anyway maybe these are duplicates anyway?

`warning: the following paths have collided (e.g. case-sensitive paths
on a case-insensitive filesystem) and only one from the same
colliding group is in the working tree:

  'chassis/cnc/CNC Parts/Rolio CNC Tapping Specification.pdf'
  'chassis/cnc/cnc parts/Rolio CNC Tapping Specification.pdf'
  'chassis/cnc/Left.step'
  'chassis/cnc/left.step'
  'chassis/cnc/Right.step'
  'chassis/cnc/right.step'
  'chassis/electronics/Left.step'
  'chassis/electronics/left.step'
  'chassis/electronics/Right.step'
  'chassis/electronics/right.step'
  'chassis/fdm/Left.step'
  'chassis/fdm/left.step'
  'chassis/fdm/Right.step'
  'chassis/fdm/right.step'`

MickiusMousius, 2023-11-29:
Fixed!

Thanks for pointing it out.

This is more a case of me being a bit silly, all duplicates, but MacOS and and case sensitivity can be a bit odd.

For what it's worth I already have inventory, so if you want one I can sort you out. Send an email to contact@keydio.io if you're interested.

Closed 2023-11-29.

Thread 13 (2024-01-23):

Any more information on the vista display modules?

milch, 2024-01-23:
Hey,

The nice!view seems to be out of stock everywhere at the moment so I've been looking at alternatives and found this repo. I unfortunately can't seem to find any more information on the Vista modules you describe via google other than a reference back to this repo, do you have any more information about it like a seller or manufacturer?

Thank you!

MickiusMousius, 2024-01-24:
Hi,

I have about 50 Vista272 modules in stock (nice view “clone”) and 150 vista508 modules.

If you’re in need I can sell you some, just reach out to contact@keydio.io and we’ll try to help.

Cheers

Ryan

joric, 2024-04-07:
@MickiusMousius are they open source? Who makes/sells them? Karnadii module doesn't seem to be size-compatible with nice!view https://github.com/joric/nrfmicro/wiki/ZMK#lcd

MickiusMousius, 2024-04-08:
Hi, they’re not open source. Though I likely will open them up soon enough. The design is pretty simple, the only value in it is the part numbers and the time taken to assemble them.

I make them, I’ve been intending to sell them via keydio.io. I have plenty of stock, but have yet to finish setting the store up as I’ve been spending a lot of time visiting a sick family member instead of working on the store.

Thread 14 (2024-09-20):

[PCB] EVQWGD001 seems to be routed/labeled incorrectly

mbiernacki89, 2024-09-20:
Hi,
Since the store seems to be delayed, I decided to build Rolio on my own.
When looking at the PCB project, I've noticed that the EVQWGD001 encoders seem to be routed incorrectly.

Comparing your schematics to the PCB:
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

Pins A and B are located in the middle of the 4-pin section, while routing on your PCB points to pin 1 and 2 (looking from the switch pins side),

Am I missing something here? (Mind you I'm a total novice when it comes to building PCBs)

MickiusMousius, 2024-09-20:
I may have something out of sync there in the repo. I’ll try and have a look this week, I’m out of town at the moment which is why I can’t look right now.

If it helps at all the only delay with the store has been getting the shopfront up. I have plenty of inventory so can ship populated and partially populated PCBs up to a fully assembled keyboard.

If you’d like more info just reach out via contact@keydio.io 😊

Cheers

Ryan

mbiernacki89, 2024-09-20:
Thanks for a fast response! :)
I've soldered the pcb In the meantime and the encoder seems to work with the routing you have there so it might have been a false alarm on my part, sorry for that.

But since we are in topic of things out of sync. It seems that `JLCPCB - Gerbers - Right` zip file actually contains files for left pcb instead. I zipped the Gerbers manually before ordering but it could be overlooked by someone

MickiusMousius, 2024-09-20:
Thanks for that, per comment left on the other issue I’ll make an effort to update the repo with all of the latest models and files.

I suspect that this might just be a footprint vs. schematic picture thing where the order of the pins in the electrical schematic may not match the  order of the pins on the physical footprint. Though  without KiCAD at hand that’s just a guess.

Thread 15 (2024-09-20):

SLS chassis - right bottom plate don't have enough space for the R3 680Ω resistor

mbiernacki89, 2024-09-20:
The right bottom plate (chassis/sls/fdm pla parts/right - bottom plate.stl) seems to not have enough space for one of the 680Ω resistors (marked R3). I had to carve a portion of it to make space for it.

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

MickiusMousius, 2024-09-20:
Ah, I’ve fixed that a long time ago.

I’ve got a lot of updated CAD models, lots of improvements have been made to the chassis and travel cases.

I think I will need to prioritise updating these repos with the newest models.

mbiernacki89, 2024-09-20:
Ah, I'm glad I havent ordered cnc chassis right away then :)

I'll be waiting for the updates, thanks for the help and quick responses

mbiernacki89, 2024-09-20:
Ah, I'm glad I havent ordered cnc chassis right away then :)

I'll be waiting for the updates, thanks for the help and quick responses

Closed 2024-09-20.

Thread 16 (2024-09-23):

Is it open source?

WMnologo, 2024-09-23:
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
Rolio46 is so cool, is this CNC file open source?

WMnologo, 2024-09-23:
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
I searched and couldn't find one of the files. Is it open source

MickiusMousius, 2024-09-24:
Ah, that one is not yet open source yet. But I’ll publish it soon. I have one more iteration to make it easier to assemble and improve Bluetooth performance.

I do have some inventory on hand though.

WMnologo, 2024-09-27:

Okay, looking forward to your open source. It's really cool and I really like it.

WMnologo, 2024-09-27:
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
Can you share this  model? I want the keyboard to be easy to carry around

MickiusMousius, 2024-09-30:
I shall, if you’re building one now let me know, otherwise I’ll try to batch it together with a bunch of other updates.

WMnologo, 2024-10-05:
Yes, I made one. Now I want this shell to be easy to carry around

MickiusMousius, 2024-10-05:
Did you make a CNC chassis or a 3D printed one?

the two travel cases have different internal dimensions.

WMnologo, 2024-10-07:
3D printed

WMnologo, 2024-10-15:
hello

MickiusMousius, 2024-10-18:
Hey, I think I have the file. But can not attach a step file here it seems.

I don’t want to put it in the repo as I have a heavily revised FDM chassis (no glue needed now) and it requires a different case.

How would you like for me to share the file to you?

WMnologo, 2024-11-14:
Have his 3D files and PCB files been open source? I try one. It's so cool.
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

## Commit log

2023-09-10 Fix some silly typos
    Incorrect resistor quantity & bad grammar
2023-10-11 Check in the 0.9 hardware
    [452403012014_Download_STP_452403012014_rev1.stp, Bottom damper.stl, Bottom insulators.stl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]
2023-10-12 Move the PCB folder to actually be "pcb"
    [452403012014_Download_STP_452403012014_rev1.stp, EVQWGD001.step, JS202011JCQN.stp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]
2023-11-22 Check in V1.0
    [Bottom damper.stl, Bottom insulators.stl, Bottom plate.stl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]
2023-11-29 Remove duplicated files
    [Left.step, Right.step]
2025-04-24 Develop (#18) Update to 1.1
    * Remove SLS option
    * Update the landing page
    * Update PCB to have nicer soldering pads for the battery
    * Update the right PCB to have a nicer set of solder pads for the battery
    * Update 3D models exports from KiCAD
    * Update JLCPCB production files
    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
    [3D Printing - PLA.3mf, 3D Printing - TPU.3mf, 3D Printing.3mf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]
